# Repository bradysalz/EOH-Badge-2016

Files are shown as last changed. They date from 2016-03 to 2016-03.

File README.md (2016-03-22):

# EOH-Badge-2016
Badges made to hand out as a teaching exercise for the IEEE UIUC exhibit at Engineering Open House 2016. When you cover up the light sensor, the badges play along and flash to "Hail to the Orange". You can see a video of the build in action [here](https://www.youtube.com/watch?v=S4cmx-UWJ_Q&feature=youtu.be). This exhibit won second place in the "Just for Fun" category!

Special thanks to [David Mellis](http://web.media.mit.edu/~mellis/) for his [attiny library](https://github.com/damellis/attiny).

# Media
Finished product

You can see a video of the exhibit in action, as well as IEEE's other exhibits [here](https://www.youtube.com/watch?v=S4cmx-UWJ_Q&feature=youtu.be).

Some excellent photos taken by Ray Chan during EOH [here](https://photos.google.com/share/AF1QipN_tZymQB7QjqU8kMJ0lrtPr13E5zKEWU58SieGECw1yZU4zlcl4fVr3wqzv2gzeQ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)

# Bugs
- Orange and Blue LED are labeled backwards, whoops!
- The 500kOhm resistor is far too large, 50k would be much better. Typo from reading the datasheet, just makes the devices extremely sensitive. 
- First note is always wrong, probably need to re-read Timer init code
- Lanyard hole is slightly too small, +5-10 mils would be better
- My initials are covered up the battery cover (this one was actually intended)

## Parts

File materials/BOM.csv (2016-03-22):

Part | Cost | Quantity | Net Cost | Supplier | URL
Coin Cell Battery | $0.23 | 400 | $93.74 | Digikey | http://www.digikey.com/product-detail/en/CR2032/P189-ND/31939
Battery Holder | $0.99 | 400 | $396.00 | Digikey | http://www.digikey.com/product-detail/en/BH32T-C/BH32T-C-ND/257745
ATtiny | $1.74 | 400 | $696.00 | Digikey | http://www.digikey.com/product-detail/en/ATTINY85V-10PU/ATTINY85V-10PU-ND/735471
Switch | $0.51 | 400 | $204.00 | Digikey | http://www.digikey.com/product-detail/en/EG1271A/EG1919-ND/251336
10kOhm Resistor | $0.02 | 400 | $7.20 | Digikey | http://www.digikey.com/product-detail/en/CFR-25JB-52-10K/10KQBK-ND/338
Blue LED | $0.23 | 400 | $90.80 | Digikey | http://www.digikey.com/product-detail/en/151053BS04500/732-5019-ND/4490021
10Ohm Resistor | $0.02 | 400 | $7.52 | Digikey | http://www.digikey.com/product-detail/en/CFR-25JB-52-10R/10QBK-ND/340
Orange Led | $0.17 | 400 | $66.80 | Digikey | http://www.digikey.com/product-detail/en/WP7113SEC/754-1271-ND/1747670
68Ohm Resistor | $0.02 | 400 | $7.52 | Digikey | http://www.digikey.com/product-detail/en/CFR-25JB-52-68R/68QBK-ND/2832
Piezo | $0.02 | 400 | $7.52 | Digikey | http://www.digikey.com/product-detail/en/PS1240P02BT/445-2525-1-ND/935930
Photodiode | $0.42 | 400 | $168.00 | Digikey | http://www.digikey.com/product-detail/en/PDV-P8104/PDV-P8104-ND/480611
510kOhm Resistor | $0.02 | 400 | $7.52 | Digikey | http://www.digikey.com/product-detail/en/CFR-25JB-52-510K/510KQBK-ND/2305
Unit Cost | $4.38 | Total Cost | $1,752.62

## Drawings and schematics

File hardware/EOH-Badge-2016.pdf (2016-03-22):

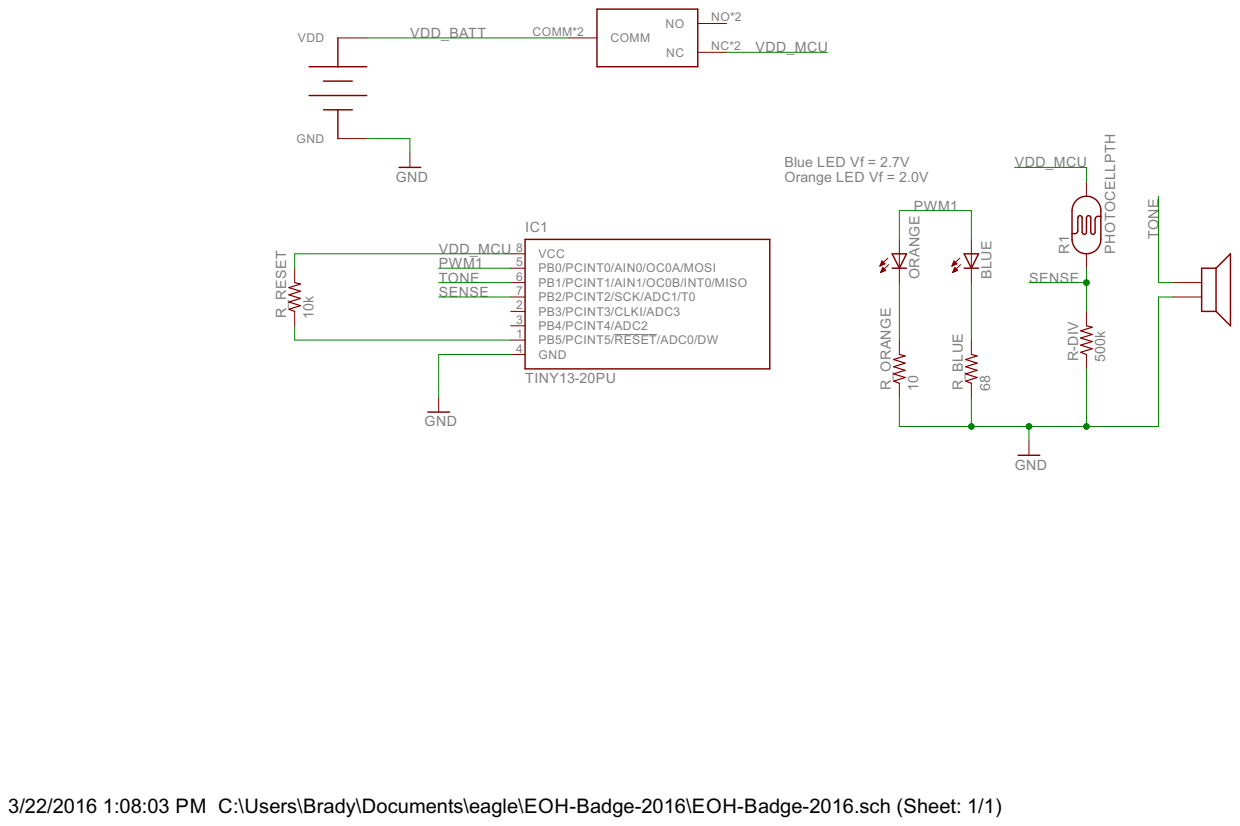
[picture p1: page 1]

3/22/2016 1:08:03 PM C:\Users\Brady\Documents\eagle\EOH-Badge-2016\EOH-Badge-2016.sch (Sheet: 1/1)

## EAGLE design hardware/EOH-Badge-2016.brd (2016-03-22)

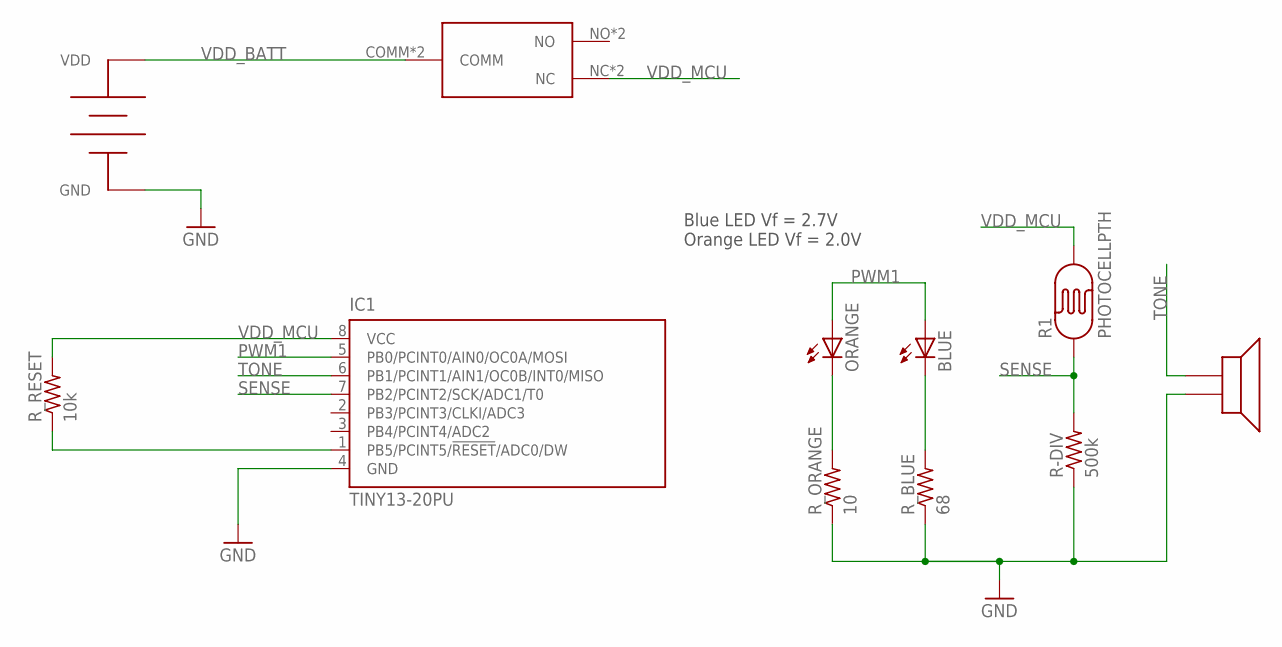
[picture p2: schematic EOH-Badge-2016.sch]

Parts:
BLUE: LED5MM
IC1: TINY13-20PU; DIL08
ORANGE: LED5MM
R1: PHOTOCELLPTH; PHOTOCELL
R-DIV: 500k; 0207/12
R_BLUE: 68; 0207/12
R_ORANGE: 10; 0207/12
R_RESET: 10k; 0207/12
U$1: MPD-BH32T-C; MPD-BC2032-E2
U$2: PIEZO; PS1240P02BT
U$3: EG1919-SW

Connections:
GND: IC1.4 (GND), R-DIV.1, R_BLUE.1, R_ORANGE.1, U$1.NEG (GND), U$2.GND
unnamed: IC1.1 (PB5/PCINT5/!RESET!/ADC0/DW), R_RESET.1
unnamed: ORANGE.K (C), R_ORANGE.2
unnamed: BLUE.K (C), R_BLUE.2
PWM1: BLUE.A, IC1.5 (PB0/PCINT0/AIN0/OC0A/MOSI), ORANGE.A
SENSE: IC1.7 (PB2/PCINT2/SCK/ADC1/T0), R1.1, R-DIV.2
TONE: IC1.6 (PB1/PCINT1/AIN1/OC0B/INT0/MISO), U$2.AUDIO
VDD_BATT: U$1.POS (VDD), U$3.COMM, U$3.COMM2 (COMM)
VDD_MCU: IC1.8 (VCC), R1.2, R_RESET.2, U$3.NC, U$3.NC2 (NC)

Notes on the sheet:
Blue LED Vf = 2.7V Orange LED Vf = 2.0V

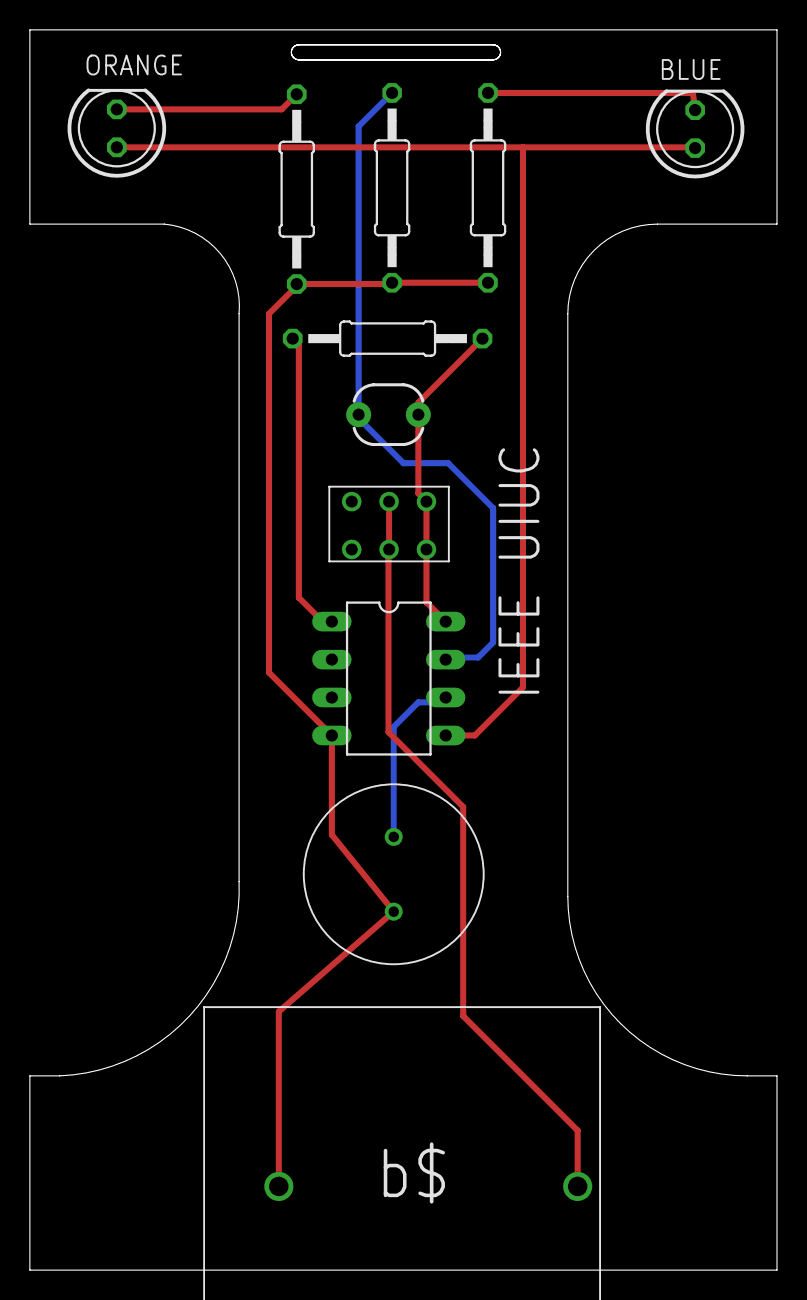
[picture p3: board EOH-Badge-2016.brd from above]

Board: 2 copper layers, 50.0 x 83.0 mm, 11 parts (0 on the bottom side), 9 nets.

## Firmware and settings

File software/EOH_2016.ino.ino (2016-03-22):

/* EOH AND CHILL 2K16
 *  AN ENDEAVOR BY BRADY SALZ
 *  AND IEEE UIUC 
 *  
 *  2/29/19
 */

// Notes
const int Note_C  = 239;
const int Note_CS = 225;
const int Note_D  = 213;
const int Note_DS = 201;
const int Note_E  = 190;
const int Note_F  = 179;
const int Note_FS = 169;
const int Note_G  = 159;
const int Note_GS = 150;
const int Note_A  = 142;
const int Note_AS = 134;
const int Note_B  = 127;

// tempos is 96 beats per minute
// 96bpm = 625ms / beat
const int beatDuration = 626; 
const int noteCount = 38;

// are counts global? now they are!
int i;

float hailToTheOrange[3*noteCount] = {
//    50, 1, 1,   // garbage note to init? didn't up working, should debug later
    Note_E, 4, 1,
    Note_A, 4, 0.75,
    Note_FS, 4, 0.25,
    Note_GS, 4, 1,
    Note_FS, 4, 1,

    Note_E, 4, 1,
    Note_A, 4, 0.75,
    Note_FS, 4, 0.25,
    Note_GS, 4, 2,

    Note_CS, 5, 2,
    Note_D, 5, 2,
    Note_CS, 5, 1,
    Note_B, 4, 0.5,
    Note_FS, 4, 1.5,

    Note_FS, 4, 2,
    Note_GS, 4, 1,
    Note_A, 4, 0.5,
    Note_B, 4, 2,

    Note_E, 4, 1,
    Note_A, 4, 0.75,
    Note_FS, 4, 0.25,
    Note_GS, 4, 1,
    Note_FS, 4, 0.75,
    Note_E, 4, 0.25,

    Note_E, 4, 0.75,
    Note_E, 4, 0.25, 
    Note_A, 4, 0.75,
    Note_FS, 4, 0.25,
    Note_GS, 4, 2,

    Note_CS, 5, 2,
    Note_D, 5, 2,
    Note_CS, 5, 1,
    Note_B, 4, 1,
    Note_A, 4, 0.5,
    Note_FS, 4, 1.5,

    Note_CS, 5, 1.5,
    Note_GS, 4, 1.5,
    Note_A, 4, 2
};


int prev_sample = 1023;
int next_sample = 1023;

void setup()
{
    DDRB |= 0x03;  // Set pins DDB0, DDB1 high (physical pins 5,6)

    TCCR1 |= (1 << PWM1A); // use Timer1, CompA in PWM Mode
    TCCR1 |= (1 << COM1A0); // Toggle 0C1A Output on match
    TCCR1 &= ~(1 << COM1A1); // Toggle the 0C1A Output on match

    GTCCR |= (1 << FOC1A); // Force output compare match 1A 
                            // makes output comparator read these settings
    PORTB &= ~(0x06);
    pinMode(A1, INPUT); // too lazy to write ADC interrupts sorry
    prev_sample = analogRead(A1);
    next_sample = analogRead(A1);
    delay(500);
}

// holders for trigger checks
int threshold = 25;
int diff = 0;

void loop()
{
    next_sample = analogRead(A1);
    diff = next_sample - prev_sample;
    
    if( diff > threshold ) // check if SENSE pin went low
    { 
      PORTB |= 0x01; // XOR toggling
      for(i = 0; i < 3*noteCount; i+=3)
      {
          
          PORTB ^= 0x01;  // XOR toggling, switch every note
//          PORTB |= 0x01; // ALL toggling, pulse every note
          myTone(hailToTheOrange[i], hailToTheOrange[i+1]-1, (int)beatDuration*hailToTheOrange[i+2]);

//          PORTB &= ~(0x01); // ALL toggling, pulse every note
          myTone(0, 4, 40);
          
      }
      delay(1000); // ensure we wait at least a second before the song starts again
                   // one might call this a literal sanity check
    }
    delay(10); // delay between samples  
    prev_sample = next_sample;
}

void myTone(unsigned char divisor, unsigned char octave, unsigned long duration)
{
    TCCR1 |= (1 << CTC1);  // Start the counter
    TCCR1 |= (1 << PWM1A); // Use PWM Mode for Timer1, OCRA
    TCCR1 &= ~(1 << COM1A0); // Toggle 0C1A Output on match
    TCCR1 |= (1 << COM1A1); // Toggle the 0C1A Output on match
    TCCR1 |= (8 - octave); // Set clock prescaler
    
    OCR1C = divisor;   // sets frequency (timer reset value)
    OCR1A = divisor/2; // set the OCR to value/2, 50% duty cycle
    delay(duration);   // play note for said duration
    TCCR1 = 0x90;      // reset + stop the counter (end PWM)
}

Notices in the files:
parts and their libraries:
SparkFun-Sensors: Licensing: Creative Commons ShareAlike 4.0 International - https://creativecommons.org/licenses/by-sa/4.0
